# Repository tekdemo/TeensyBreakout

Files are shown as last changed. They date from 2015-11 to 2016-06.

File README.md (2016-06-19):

# Teensy Breakout

A small PCB to break out a Teensy into a form factor suitable for small electronics prototyping

# Features
- Adapts Teensy pinout to Arduino shield, so existing shields can be fit to a Teensy
- Adds LiPo battery monitoring and charging capability
- Adds three wire pinouts for all pins
- All PWM outputs have an LED
- All PWM outputs connect to 3 wire servo headers that supply input or battery voltage for use with servos or motor controllers
- Contains small Stormy logo on back since the [Stormbots](http://stormbots.com) were the inspiration for this board's existence

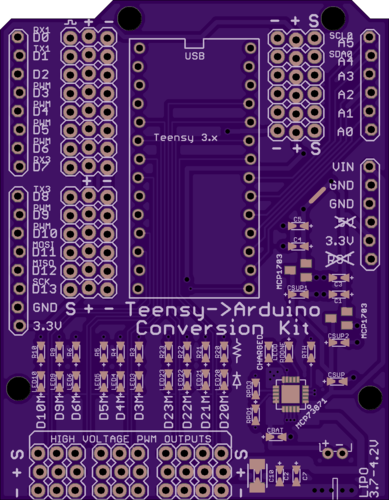
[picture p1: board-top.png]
Board Top
 

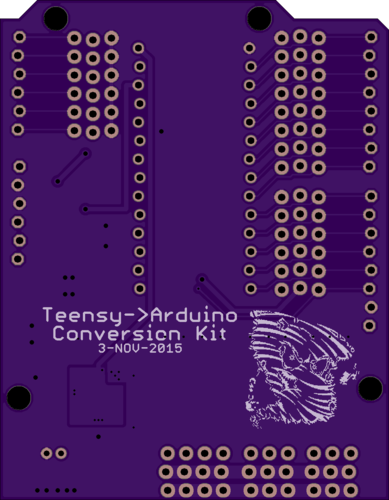
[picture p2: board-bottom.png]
Board Bottom
 

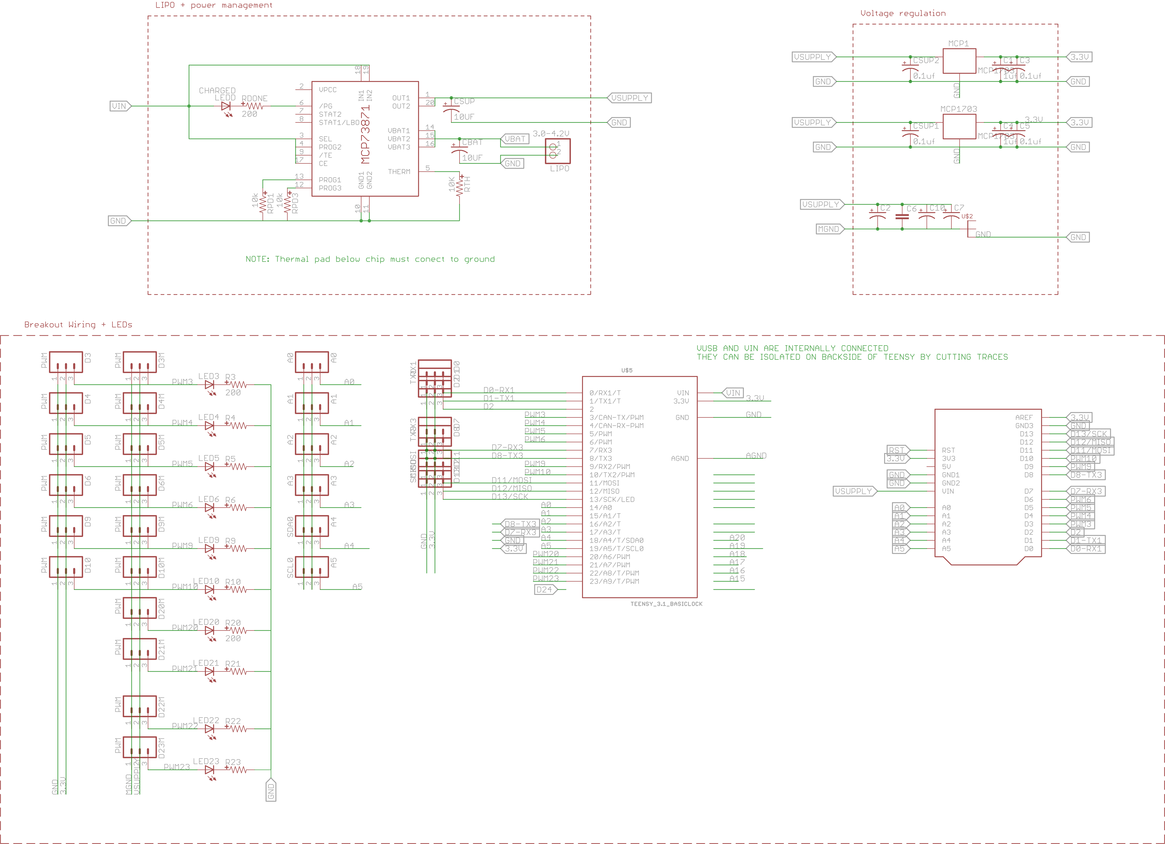
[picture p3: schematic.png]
Schematic


# BOM
Due to the nature of the breakout, many components can be omitted depending on the needed sections. 

## Components 
 Part | Quantity  | Description | Part Number
---|---|---|---
 Teensy | 1 | Teensy Microcontroller | [OSH Park][oshteensy] or [Adafruit][adateensy] or 
PCB | 1 | Bare PCB | [OSH Park][pcb]
LED |11| 0603 or 0805 LED | any
1uF cap  |2| 0603 or 0805 cap | any
0.1uF cap |4| 0603 or 0805 LED | any
10uF cap |2| 0603 or 0805 cap | any
LiPO Battery |4| Any with JST connector | [Adafruit][lipo]
JST Battery Connector |4|  | [JST-PH-2-THM-RA][JST-PH-2-THM-RA]
MCP73871| 2 | LiPO Battery Management IC | [MCP73871][MCP73871]
MCP1703| 2 | 3.3V voltage regulator | [MCP1703][MCP1703]
Large (100uF+ cap) |2| 0603 or larger | any

## Pin Connections
The various use cases may or may not require some or all of these pins. Here's the most you can solder to the board in the simplest orientation

Most of these can be swapped, omitted, or assembled with small 1x3 connectors or whatever you have on hand. Otherwise, they can be purchased at [Digikey](http://digikey.com) or [Adafruit](http://adafruit.com)

Part | Quantity  | Description 
---|---|---
Arduino Sockets | 2 | 0.1" 1x8 F socket 
Arduino Sockets | 2 | 0.1" 1x6 F socket 
3 wire output headers | 2 | 0.1" 3x8 M Angle Pins 
3 wire output headers | 1 | 0.1" 3x6 M Angle Pins 
Servo output headers | 2 | 0.1" 3x3 M 90 degree Pins 
Servo output headers | 1 | 0.1" 3x4 M 90 degree Pins 

[oshteensy]: http://store.oshpark.com/products/teensy-3-1
[adateensy]: https://www.adafruit.com/product/2756
[pcb]: https://oshpark.com/import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
[lipo]: https://www.adafruit.com/categories/574
[MCP1703]: http://www.digikey.com/product-detail/en/microchip-technology/MCP1703AT-3302E-CB/MCP1703AT-3302E-CBCT-ND/3598398
[MCP73871]: http://www.digikey.com/product-detail/en/microchip-technology/MCP73871-2CCI-ML/MCP73871-2CCI-ML-ND/1680971
[JST-PH-2-THM-RA]: http://www.digikey.com/product-detail/en/jst-sales-america-inc/S2B-PH-K-S(LF)(SN)/455-1719-ND/926626

# Special Thanks

Thanks to Adafruit, who supplied the base schematic for the Battery monitor IC. Awesome work.

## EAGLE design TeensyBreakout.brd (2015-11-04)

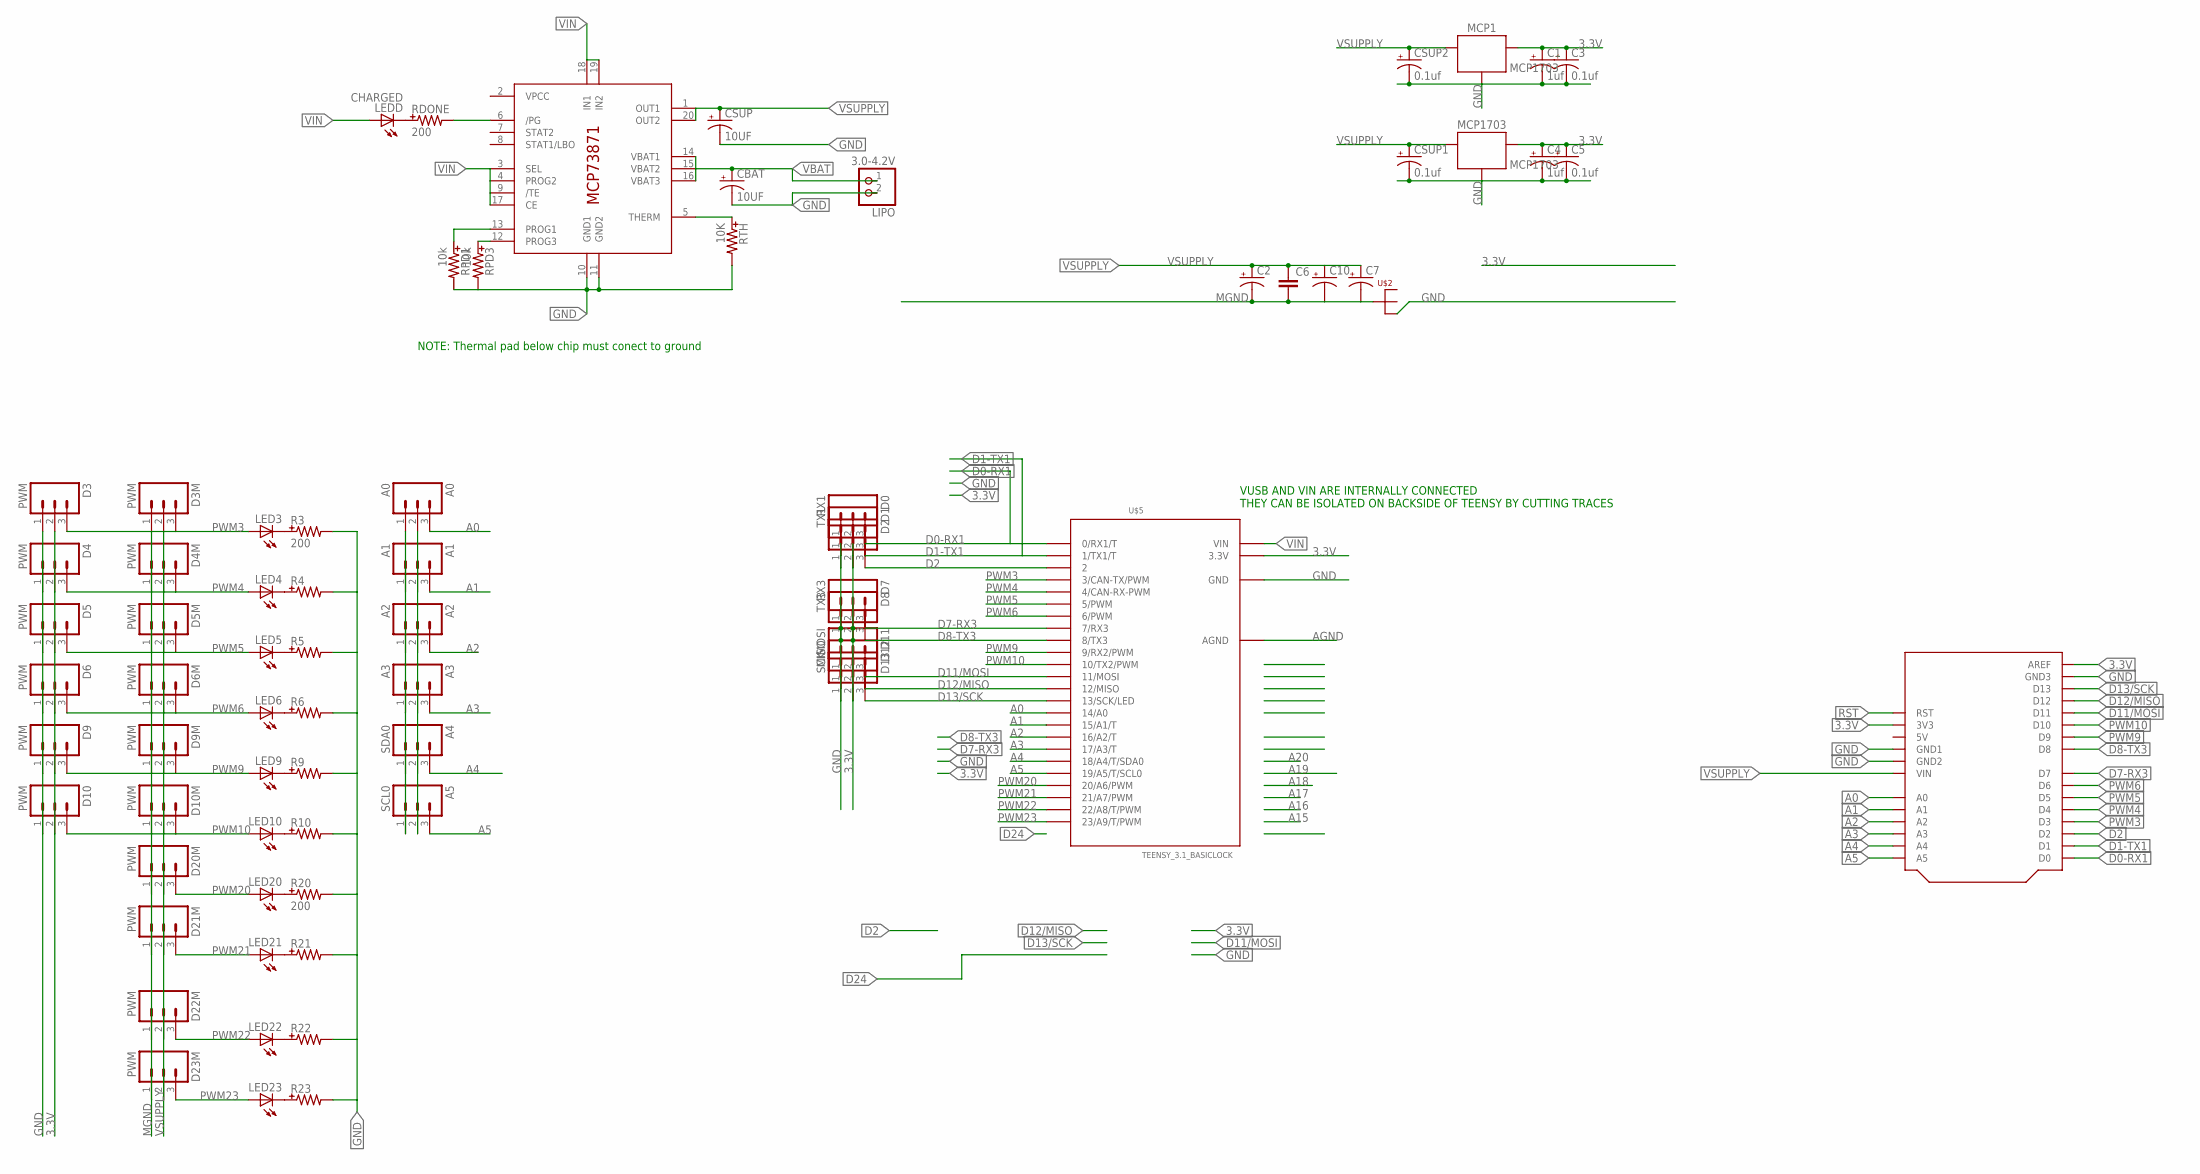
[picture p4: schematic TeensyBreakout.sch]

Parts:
A0: A0; 1X03_LOCK
A1: A1; 1X03_LOCK
A2: A2; 1X03_LOCK
A3: A3; 1X03_LOCK
A4: SDA0; 1X03_LOCK
A5: SCL0; 1X03_LOCK
C1, C4: 1uf; 0402-0603-0805-UNIVERSAL
C2, C7, C10: CAP-POLARIZEDUNIVERSAL; 0402-0603-0805-UNIVERSAL
C3, C5: 0.1uf; 0402-0603-0805-UNIVERSAL
C6: CAP1210; 1210
CBAT: 10UF; 0402-0603-0805-UNIVERSAL
CSUP: 10UF; 0402-0603-0805-UNIVERSAL
CSUP1, CSUP2: 0.1uf; 0402-0603-0805-UNIVERSAL
D0: RX1; 1X03_LOCK
D1: TX1; 1X03_LOCK
D2: M03LOCK; 1X03_LOCK
D3, D3M, D4, D4M, D5, D5M, D6, D6M, D9, D9M, D10, D10M, D20M, D21M, D22M, D23M: PWM; 1X03_LOCK
D7: RX3; 1X03_LOCK
D8: TX3; 1X03_LOCK
D11: MOSI; 1X03_LOCK
D12: MISO; 1X03_LOCK
D13: SCK; 1X03_LOCK
IC1: MCP73871; QFN20
LED3, LED4, LED5, LED6, LED9, LED10, LED20, LED21, LED22, LED23: LEDUNIVERSAL; 0402-0603-0805-UNIVERSAL
LEDD: CHARGED; 0402-0603-0805-UNIVERSAL
LIPO: 3.0-4.2V; JST-PH-2-THM-RA
MCP1, MCP1703: MCP1703; SOT23
R3, R20: 200; 0402-0603-0805-UNIVERSAL
R4, R5, R6, R9, R10, R21, R22, R23: RESISTORUNIVERSAL; 0402-0603-0805-UNIVERSAL
RDONE: 200; 0402-0603-0805-UNIVERSAL
RPD1, RPD3: 10k; 0402-0603-0805-UNIVERSAL
RTH: 10K; 0402-0603-0805-UNIVERSAL
U$2: NET-JUNCTION8-MIL-DIAMETER; NET-JUNCTION
U$4: ARDUINO
U$5: TEENSY_3.1_BASICLOCK; TEENSY_3.1_BASIC_LOCK

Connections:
3.3V: A0.2, A1.2, A2.2, A3.2, A4.2, A5.2, C1.+, C3.+, C4.+, C5.+, D0.2, D1.2, D2.2, D3.2, D4.2, D5.2, D6.2, D7.2, D8.2, D9.2, D10.2, D11.2, D12.2, D13.2, MCP1.2 (OUT), MCP1703.2 (OUT), U$4.3V3, U$4.AREF, U$5.3.3V
A0: A0.3, U$4.A0, U$5.14/A0
A1: A1.3, U$4.A1, U$5.15/A1 (15/A1/T)
A2: A2.3, U$4.A2, U$5.16/A2 (16/A2/T)
A3: A3.3, U$4.A3, U$5.17/A3 (17/A3/T)
A4: A4.3, U$4.A4, U$5.18/A4 (18/A4/T/SDA0)
A5: A5.3, U$4.A5, U$5.19/A5 (19/A5/T/SCL0)
AGND: U$5.AGND
D0-RX1: D0.3, U$4.D0, U$5.0 (0/RX1/T)
D1-TX1: D1.3, U$4.D1, U$5.1 (1/TX1/T)
D2: D2.3, U$4.D2, U$5.2
D7-RX3: D7.3, U$4.D7, U$5.7 (7/RX3)
D8-TX3: D8.3, U$4.D8, U$5.8 (8/TX3)
D11/MOSI: D11.3, U$4.D11, U$5.11 (11/MOSI)
D12/MISO: D12.3, U$4.D12, U$5.12 (12/MISO)
D13/SCK: D13.3, U$4.D13, U$5.13 (13/SCK/LED)
GND: A0.1, A1.1, A2.1, A3.1, A4.1, A5.1, C1.-, C3.-, C4.-, C5.-, CBAT.-, CSUP.-, CSUP1.-, CSUP2.-, D0.1, D1.1, D2.1, D3.1, D4.1, D5.1, D6.1, D7.1, D8.1, D9.1, D10.1, D11.1, D12.1, D13.1, IC1.10 (GND1), IC1.11 (GND2), LIPO.2 (1), MCP1.1 (GND), MCP1703.1 (GND), R3.- (2), R4.- (2), R5.- (2), R6.- (2), R9.- (2), R10.- (2), R20.- (2), R21.- (2), R22.- (2), R23.- (2), RPD1.- (2), RPD3.- (2), RTH.- (2), U$2.P$4 (3), U$4.GND1, U$4.GND2, U$4.GND3, U$5.GND
MGND: C2.-, C6.2, C7.-, C10.-, D3M.1, D4M.1, D5M.1, D6M.1, D9M.1, D10M.1, D20M.1, D21M.1, D22M.1, D23M.1, U$2.P$1 (1)
unnamed: IC1.5 (THERM), RTH.+ (1)
unnamed: IC1.12 (PROG3), RPD3.+ (1)
unnamed: IC1.13 (PROG1), RPD1.+ (1)
unnamed: IC1.6 (/PG), RDONE.- (2)
unnamed: LEDD.- (C), RDONE.+ (1)
unnamed: LED3.- (C), R3.+ (1)
unnamed: LED4.- (C), R4.+ (1)
unnamed: LED5.- (C), R5.+ (1)
unnamed: LED6.- (C), R6.+ (1)
unnamed: LED9.- (C), R9.+ (1)
unnamed: LED10.- (C), R10.+ (1)
unnamed: LED20.- (C), R20.+ (1)
unnamed: LED21.- (C), R21.+ (1)
unnamed: LED22.- (C), R22.+ (1)
unnamed: LED23.- (C), R23.+ (1)
PWM3: D3.3, D3M.3, LED3.+ (A), U$4.D3, U$5.3 (3/CAN-TX/PWM)
PWM4: D4.3, D4M.3, LED4.+ (A), U$4.D4, U$5.4 (4/CAN-RX-PWM)
PWM5: D5.3, D5M.3, LED5.+ (A), U$4.D5, U$5.5 (5/PWM)
PWM6: D6.3, D6M.3, LED6.+ (A), U$4.D6, U$5.6 (6/PWM)
PWM9: D9.3, D9M.3, LED9.+ (A), U$4.D9, U$5.9 (9/RX2/PWM)
PWM10: D10.3, D10M.3, LED10.+ (A), U$4.D10, U$5.10 (10/TX2/PWM)
PWM20: D20M.3, LED20.+ (A), U$5.20/A6 (20/A6/PWM)
PWM21: D21M.3, LED21.+ (A), U$5.21/A7 (21/A7/PWM)
PWM22: D22M.3, LED22.+ (A), U$5.22/A8 (22/A8/T/PWM)
PWM23: D23M.3, LED23.+ (A), U$5.23/A9 (23/A9/T/PWM)
RST: U$4.RST
VBAT: CBAT.+, IC1.14 (VBAT1), IC1.15 (VBAT2), IC1.16 (VBAT3), LIPO.1 (2)
VIN: IC1.3 (SEL), IC1.4 (PROG2), IC1.9 (/TE), IC1.17 (CE), IC1.18 (IN1), IC1.19 (IN2), LEDD.+ (A), U$5.VIN
VSUPPLY: C2.+, C6.1, C7.+, C10.+, CSUP.+, CSUP1.+, CSUP2.+, D3M.2, D4M.2, D5M.2, D6M.2, D9M.2, D10M.2, D20M.2, D21M.2, D22M.2, D23M.2, IC1.1 (OUT1), IC1.20 (OUT2), MCP1.3 (IN), MCP1703.3 (IN), U$4.VIN

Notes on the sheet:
VUSB AND VIN ARE INTERNALLY CONNECTED THEY CAN BE ISOLATED ON BACKSIDE OF TEENSY BY CUTTING TRACES
NOTE: Thermal pad below chip must conect to ground

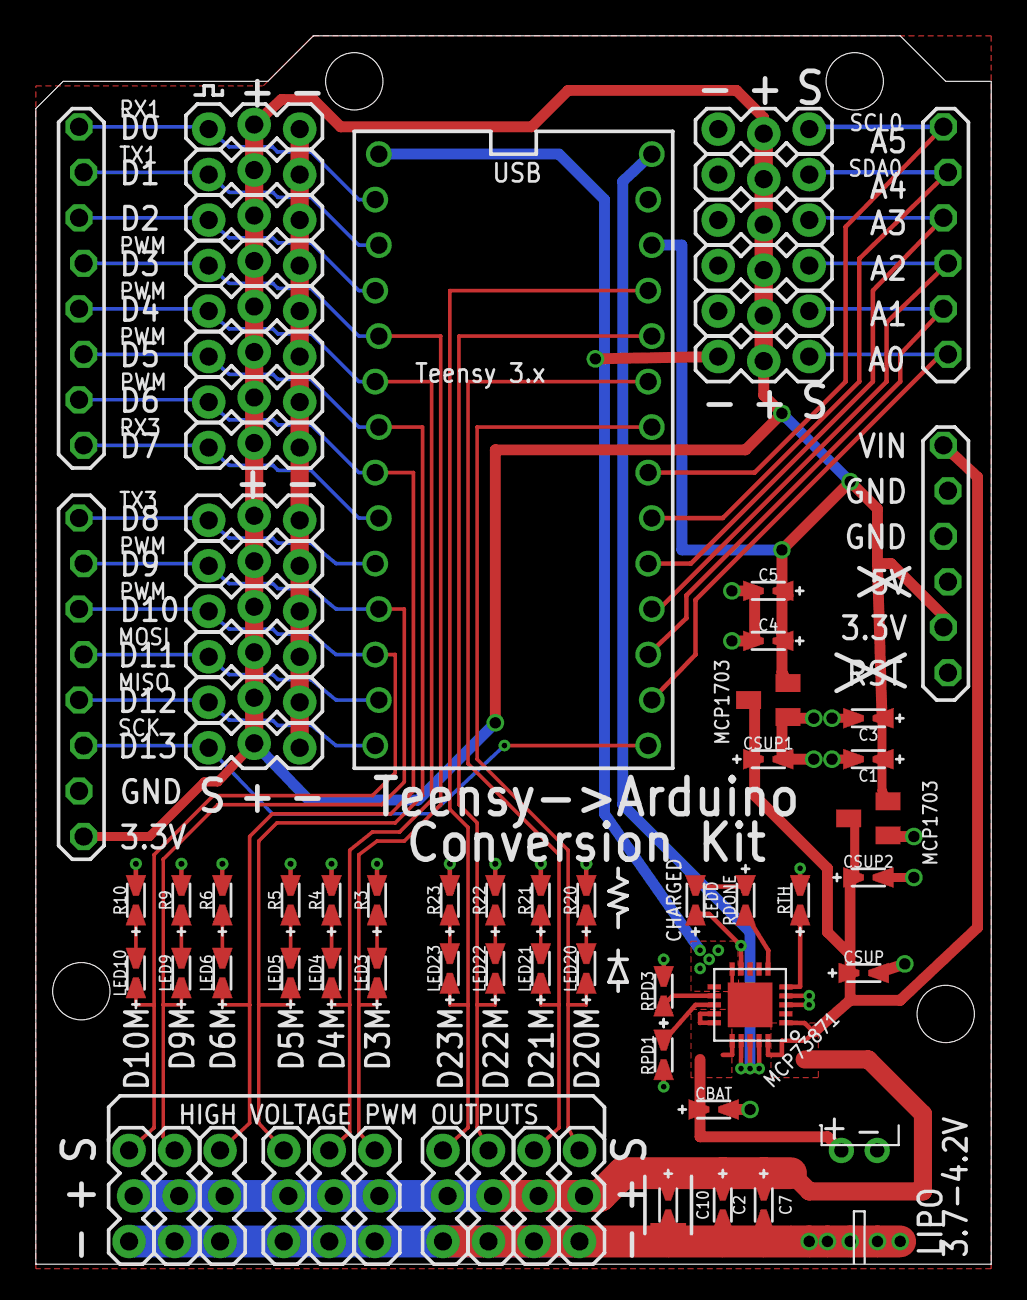
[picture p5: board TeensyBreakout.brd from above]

Board: 2 copper layers, 53.3 x 68.6 mm, 74 parts (0 on the bottom side), 45 nets.

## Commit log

2015-11-04 Update locking headers, fix 2 missing wires
    [TeensyBreakout.brd, TeensyBreakout.sch]
2016-06-19 Improve documentation
    [TeensyBreakout.sch]
2016-06-19 Add BOM
